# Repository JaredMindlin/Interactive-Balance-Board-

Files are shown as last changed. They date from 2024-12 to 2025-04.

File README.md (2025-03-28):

**Montessori Interactive Balance Board App**
This project is part of the Montessori Interactive Balance Board System, which aims to provide an engaging, technology-enhanced educational tool for children. The app serves as the primary interface for interacting with the system, enabling game selection, system control, and real-time status updates of connected devices.

**Features: ✅ Completed Features**<br /><br />

**System Control Dashboard:**
* Toggle system ON/OFF and manage connections to devices (ESP32 boards).
* Display the count of connected devices in real-time.
* Monitor and control the system's LED status.

**Game Modes:**<br />
Pathway Game: Guide the user from a starting point (green node) to a destination (red node) via blue LED pathways (placeholder created).<br />
Up Next Game: Sequentially guide the user through a series of dynamically changing nodes (placeholder created).<br />

**Database Integration:**
Real-time updates of system and game states using MongoDB.<br />
Persistent storage for:<br />
* System status (ON/OFF).
* Connected devices count.
* LED state.
* Selected game mode.

**Frontend-Backend Communication:**
* API integration between the React frontend and the Node.js/Express backend.
* Live updates to the backend state via Axios.

**ESP32 Hardware Perception and Output**
* Connected NeoPixel Strip and HC-SR01 ultrasonic distance sensors to the WSP32 Firebeetle using SPI and Arduino Libraries. The LED Strip reflects the distance detected by each distance sensor. 

**Wi-Fi/Bluetooth Integration: 🚧 In Progress**
* Communication between the app and the ESP32 server for real-time hardware interaction.
* Enable hardware-triggered events and feedback.

**Game Interactions:**
* Fully interactive gameplay tied to hardware input/output (e.g., LED activation and sensor feedback).
* Dependency on ESP32 connections and hardware setup.

**Installation and Setup:**

**Prerequisites**
* Node.js and npm/yarn installed on your system.
* MongoDB Atlas account or a locally hosted MongoDB instance.
* ESP32 with Arduino IDE configured for Wi-Fi/Bluetooth communication.

**Steps**
Clone the repository:
* git clone https://github.com/JaredMindlin/Interactive-Balance-Board-.git
* cd Interactive-Balance-Board

Install dependencies for both frontend and backend:
* cd montessori-app/frontend
* npm install
* cd ../backend
* npm install

Start the MongoDB database connection and backend server:
* cd ../backend
* node server.js

Start the frontend development server:
* cd ../frontend
* npm start

Access the app at http://localhost:3000 locally or http://'your.network.ip':3000.

**Usage**
* Navigate to the System Control page to manage the system's state and connected devices.
* Select a game mode from the Game Modes page. Changes will reflect in the database.
* Monitor real-time system updates and continue further Wi-Fi/Bluetooth integration.

**Future Goals**
* Finalize hardware communication for seamless interaction between the app and the ESP32 server.
* Enhance gameplay by incorporating live feedback from sensors and LEDs.
* Improve UI/UX based on user testing and feedback.

**All Known Bugs**
* Apart from placeholders for 'In Progress' work, inexpected behavior currently only lies in communicating with the ESP32 Server Board to actually track the real-time user data.<br />
* We have attempted to integrate the app to have access to HTTP requests made by the board to update the backend database and trigger the board to dequeue and sleep its process, however this feature has been moved under 'In Progress' by the team.
* When connected to battery, the LED strip randomly lights blue and purple when a close distance is detected. (More lights turn on) Likely due to a lack of power to the LED strip.

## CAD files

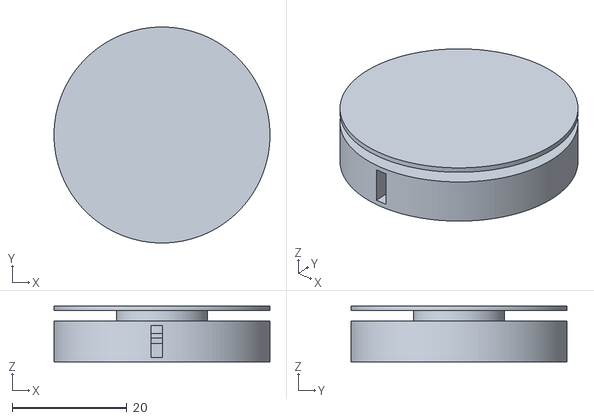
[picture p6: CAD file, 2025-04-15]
Models and Schematics/Velostat Sensor Case/Sensor Case Assembly.stl
37.6 x 37.6 x 9.71

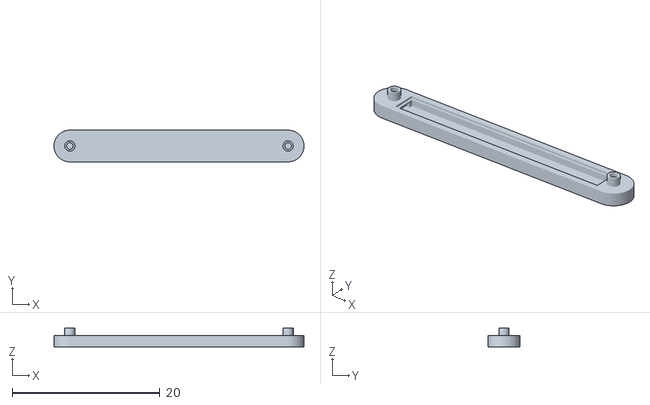
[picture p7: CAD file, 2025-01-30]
Models and Schematics/Montessori Board Model 0.1/Part Studio 1 - Part 1.stl
33.8 x 4.30 x 2.52

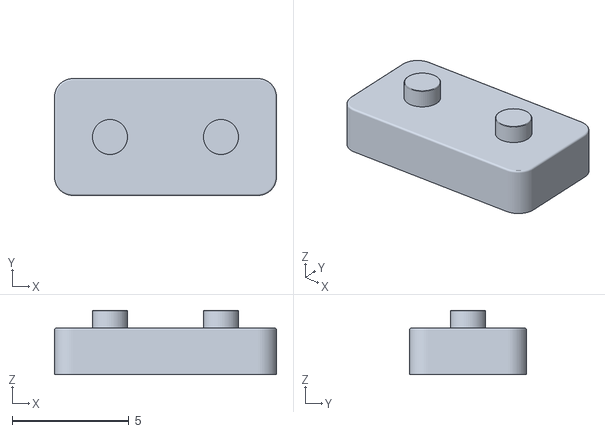
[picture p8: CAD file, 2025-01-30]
Models and Schematics/Montessori Board Model 0.2/Part Studio 1 - Base.stl
9.50 x 5.00 x 2.75

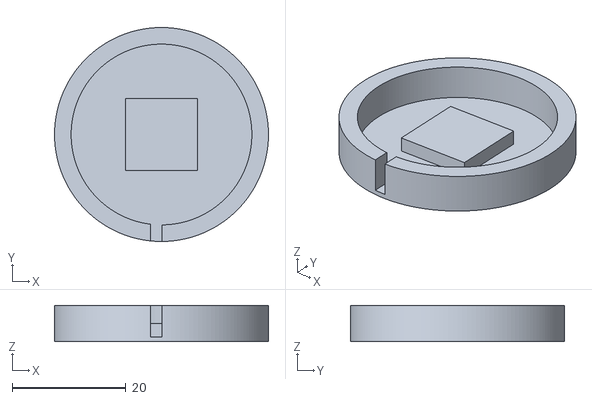
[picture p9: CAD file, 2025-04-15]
Models and Schematics/Velostat Sensor Case/Board - Sensor Base.stl
37.6 x 37.6 x 6.35

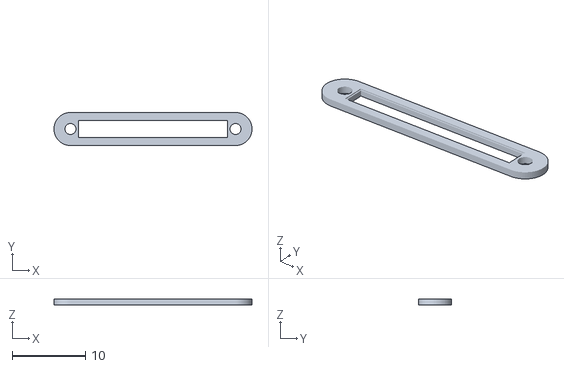
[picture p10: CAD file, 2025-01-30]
Models and Schematics/Montessori Board Model 0.2/Part Studio 1 - Top.stl
27.0 x 4.50 x 0.75

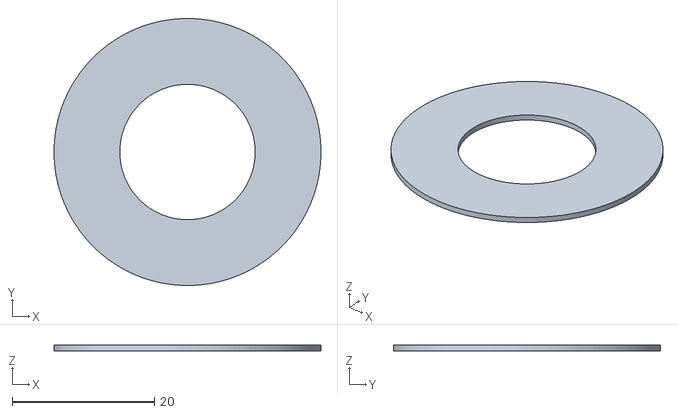
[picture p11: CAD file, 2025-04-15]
Models and Schematics/Velostat Sensor Case/Board - Sensor Lid.stl
37.6 x 37.6 x 0.794

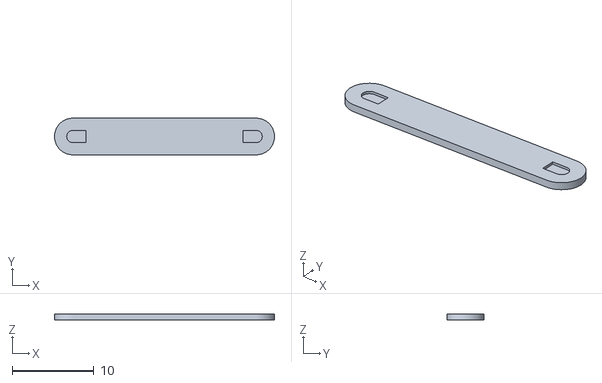
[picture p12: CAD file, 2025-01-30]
Models and Schematics/Montessori Board Model 0.2/Part Studio 1 - Bottom.stl
27.0 x 4.50 x 0.75

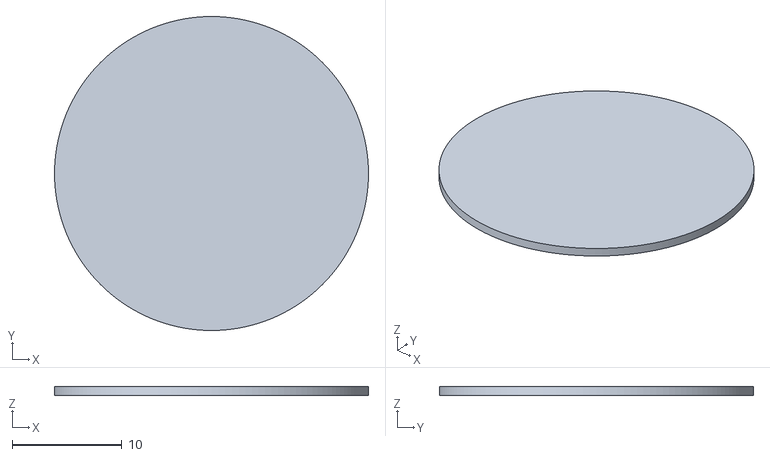
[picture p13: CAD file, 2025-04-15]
Models and Schematics/Velostat Sensor Case/Board - Velostat Top Pad.stl
28.6 x 28.6 x 0.794

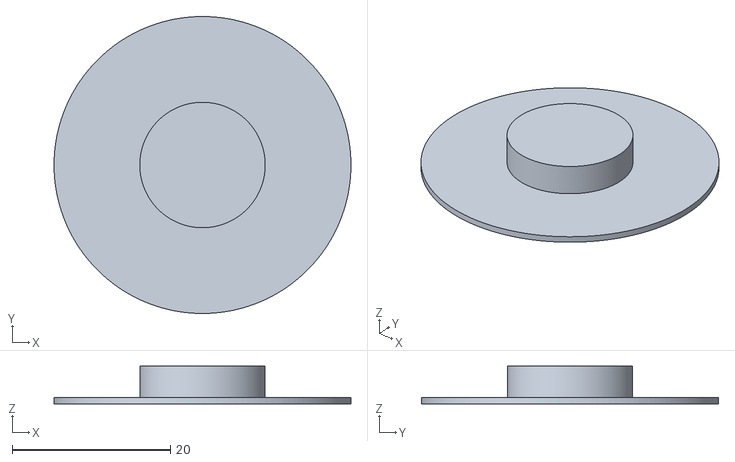
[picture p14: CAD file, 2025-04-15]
Models and Schematics/Velostat Sensor Case/Board - Sensor Top Pad.stl
37.6 x 37.6 x 4.76

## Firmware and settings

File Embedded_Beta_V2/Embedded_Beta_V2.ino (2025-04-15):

// Wifi Library/Header File
#include <WiFi.h>
// Http communication Library/Header File
#include <HTTPClient.h>
// JSON for Arduino Library/Header File
#include <ArduinoJson.h>
// Arduino LED Strip Library/Header File
#include <Adafruit_NeoPixel.h>
// Wifi Library Mananger for SSID and password security
#include <WiFiManager.h>
// String is Numeric Checker
#include <ctype.h>

#define PIN_NEO_PIXEL 2  // The ESP32 pin GPIO2 connected to NeoPixel
#define NUM_PIXELS 30     // The number of LEDs (pixels) on NeoPixel LED strip

// Node.JS Backend Server Routes
#define SERVER_URL "http://172.20.10.6:5000/update-device-count"

String ipAddress;
String GameAddress = ":5000/game-mode";
String BrightnessAddress = ":5000/brightness";
String FetchBoardIDAddress = ":5000/api/board/register-board";
String FetchBoardZeroDataAddress = ":5000/api/board/board-valid-data-zero";
String FetchBoardZeroEndAddress = ":5000/api/board/board-end-data-zero";
String FetchBoardOneDataAddress = ":5000/api/board/board-valid-data-one";
String FetchBoardOneEndAddress = ":5000/api/board/board-end-data-one";
String FetchBoardTwoDataAddress = ":5000/api/board/board-valid-data-two";
String FetchBoardTwoEndAddress = ":5000/api/board/board-end-data-two";


int pressurePin = A0;
Adafruit_NeoPixel NeoPixel(NUM_PIXELS, PIN_NEO_PIXEL, NEO_GRB + NEO_KHZ800);
int boardBrightness = 255;

// Define States for the State Machine for the boards
enum BoardStates {ON, CONNECTED, PATHWAY, UPNEXT};
BoardStates currentState = ON;

// Default Board ID before being assigned a real ID
int boardID = -1;

// Default GameMode (used for switching)
int lastGameMode = -1;
// Default Brightness
int currentBrightness = 255;
// Brightness Changes
int convBrightness = 100;
// Game Speed
int gameSpeed = 5000;

// Game Variables
bool isBoardValid = false;
bool isBoardEndPoint = false;

// Game Functions
void resetBoards() {
  currentState = CONNECTED;
  isBoardValid = false;
  isBoardEndPoint = false;
}

void youLose() {
  setLEDs(255, 0, 0); // Red
  delay(5000);
  resetBoards();
}

void youWin() {
  setLEDs(0, 255, 0); // Green
  delay(5000);
  resetBoards();
}

// Define Helper Functions
void updateRoutes() {
  GameAddress = "http://" + ipAddress + GameAddress;
  BrightnessAddress = "http://" + ipAddress + BrightnessAddress;
  FetchBoardIDAddress = "http://" + ipAddress + FetchBoardIDAddress;
  FetchBoardZeroDataAddress = "http://" + ipAddress + FetchBoardZeroDataAddress;
  FetchBoardZeroEndAddress = "http://" + ipAddress + FetchBoardZeroEndAddress;
  FetchBoardOneDataAddress = "http://" + ipAddress + FetchBoardOneDataAddress;
  FetchBoardOneEndAddress = "http://" + ipAddress + FetchBoardOneEndAddress;
  FetchBoardTwoDataAddress = "http://" + ipAddress + FetchBoardTwoDataAddress;
  FetchBoardTwoEndAddress = "http://" + ipAddress + FetchBoardTwoEndAddress;
  // Serial.println("Game Address: " + GameAddress);
  // Serial.println("Brightness Address: " + BrightnessAddress);
  // Serial.println("Fetch Board ID Address: " + FetchBoardIDAddress);
  // Serial.println("Fetch Board 0 Data Address: " + FetchBoardZeroDataAddress);
  // Serial.println("Fetch Board 0 End Address: " + FetchBoardZeroEndAddress);
  // Serial.println("Fetch Board 1 Data Address: " + FetchBoardOneDataAddress);
  // Serial.println("Fetch Board 1 End Address: " + FetchBoardOneEndAddress);
  // Serial.println("Fetch Board 2 Data Address: " + FetchBoardTwoDataAddress);
  // Serial.println("Fetch Board 2 End Address: " + FetchBoardTwoEndAddress);
}

void setLEDs(uint8_t r, uint8_t g, uint8_t b) {
  for (int pixel = 0; pixel < NUM_PIXELS; pixel++) {
      NeoPixel.setPixelColor(pixel, NeoPixel.Color(r, g, b));
  }
}

// Function that converts user input (1-100) into the range of (1-255)
void adjustBrightness(int &currBrightness, int nodePacket) {
  float conversion = (nodePacket / 100.0) * 255;
  currBrightness = (int)conversion;
  // Brightness is first applied
  NeoPixel.setBrightness(currBrightness);
}

void PathWayGameMode() {
  int sensorValue = analogRead(pressurePin);
  Serial.println(sensorValue);
  if (isBoardValid) {
    if (sensorValue > 300) {
      if (isBoardEndPoint) {
        youWin();
      }
      else {
        setLEDs(128, 0, 128); // Purple 
      }
    }
    else {
      setLEDs(0, 0, 255); // Blue
    }
  }
  else {
    if (sensorValue > 300) {
      youLose();
    }
  }
  delay(1000);
}

void UpNextGameMode() {
  int sensorValue = analogRead(pressurePin);
  Serial.println(sensorValue);
  if (isBoardEndPoint && sensorValue > 300) {
    youWin();
  }
  else {
    if (sensorValue > 300) {
      setLEDs(64, 224, 208); // Turqoise
    }
    else {
      setLEDs(255, 140, 0); // Dark Orange
    }
  }
  delay(1000);
}

// HTTP Post Function
void sendDataToServer() {
  if (WiFi.status() == WL_CONNECTED) {
    Serial.println("WiFi Connected, attempting HTTP POST...");

    HTTPClient http;
    http.begin(SERVER_URL);  // Ensure this URL is correct
    http.addHeader("Content-Type", "application/json");

    String jsonPayload = "{\"device\": \"ESP32\"}";
    Serial.print("Sending data: ");
    Serial.println(jsonPayload);

    int httpResponseCode = http.POST(jsonPayload);

    Serial.print("HTTP Response code: ");
    // If -1, request failed
    Serial.println(httpResponseCode);  
    http.end();
  }
  else {
    Serial.println("WiFi Disconnected, unable to send data.");
  }
}

// HTTP Post Function
void sendBoardStatusToServer(String boardID, bool isOccupied) {
  if (WiFi.status() == WL_CONNECTED) {
    HTTPClient http;
    http.begin(SERVER_URL);
    http.addHeader("Content-Type", "application/json");

    String jsonPayload = "{\"boardID\": \"" + boardID + "\", \"isOccupied\": " + (isOccupied ? "true" : "false") + "}";
    Serial.print("Sending data: ");
    Serial.println(jsonPayload);

    int httpResponseCode = http.POST(jsonPayload);
    Serial.print("HTTP Response code: ");
    // If -1, request failed
    Serial.println(httpResponseCode);  
    if (httpResponseCode == 200) {
      // We'll see where this goes
    }
    http.end();
  }
}

// HTTP Request for checking brightness
void fetchBrightness() {
  if (WiFi.status() == WL_CONNECTED) {
      HTTPClient http;
      http.begin(BrightnessAddress);
      
      int httpResponseCode = http.GET();  // Send GET request

      if (httpResponseCode > 0) {
          String response = http.getString();
          Serial.println("Brightness Response: " + response);
          String delimiter1 = ":";
          String delimiter2 = "}";
          int pos1 = response.indexOf(delimiter1);
          int pos2 = response.indexOf(delimiter2, pos1 + 1); // Start searching after the first delimiter
          String substring = response.substring(pos1 + 1, pos2);
          int brightness = substring.toInt();
          if (brightness >= 1 && brightness <= 100 && brightness != convBrightness) {
            adjustBrightness(currentBrightness, brightness);
            convBrightness = brightness;
            Serial.printf("New Brightness: %d\n", brightness);
          }
      }
      else {
        Serial.println("HTTP Request for brightness failed");
      }    
      http.end();
  } 
  else {
    Serial.println("WiFi Disconnected - Brightness");
  }
}

// HTTP request for game mode
void fetchGameMode() {
    if (WiFi.status() == WL_CONNECTED) {
      HTTPClient http;
      http.begin(GameAddress);
      int httpResponseCode = http.GET();  // Send GET request
      int tempGameMode = lastGameMode; // Variable to prevent constant gamemode reassignment
      if (httpResponseCode > 0) {
        String response = http.getString();
        if (response.equals("{\"gameModeSelected\":\"Pathway\"}")) {
          lastGameMode = 1;
        }
        else if (response.equals("{\"gameModeSelected\":\"UpNext\"}")) {
          lastGameMode = 2;
        }
        else {
          lastGameMode = 0;
        }
        if (tempGameMode != lastGameMode) {
          switch (lastGameMode) {
          case 0:
            currentState = CONNECTED;
            break;
          case 1:
          // GET PULL BOARD DATA
            fetchBoardData();
            currentState = PATHWAY;
            break;
          case 2:
            // GET PULL BOARD DATA
            fetchBoardData();
            currentState = UPNEXT;
            break;
          default:
            currentState = CONNECTED;
            break;
          }
        }
      }
      else {
        Serial.println("HTTP Request failed");
      }
      http.end();
  } 
  else {
    Serial.println("WiFi Disconnected - Gamemode");
  }
}

// HTTP Request for assigning boardID
void fetchBoardID() {
  if (WiFi.status() == WL_CONNECTED) {
      HTTPClient http;
      http.begin(FetchBoardIDAddress);
      
      int httpResponseCode = http.GET();  // Send GET request
      if (httpResponseCode > 0) {
        String response = http.getString();
        Serial.println("ID Response: " + response);
        char capture = response.substring(response.length() - 2, response.length() - 1).charAt(0);
        if (isdigit(capture)) {
          int tempID = capture - '0';
          Serial.printf("Captured Number: %d\n", tempID);
          if (boardID == -1) {
            boardID = tempID;
          }
        }
      }
      else {
        Serial.println("HTTP Request for boardID failed");
      }
      http.end();
  } 
  else {
    Serial.println("WiFi Disconnected - BoardID");
  }
}

// HTTP Request for retreiving the vector of valid boards
void fetchBoardData() {
  if (WiFi.status() == WL_CONNECTED) {
    String delimiter1 = ":";
    String delimiter2 = "}";
    int pos1;
    int pos2;
    String substring;
    HTTPClient http;
    if (boardID == 0) {
      http.begin(FetchBoardZeroDataAddress);
    }
    else if (boardID == 1) {
      http.begin(FetchBoardOneDataAddress);
    }
    else if (boardID == 2) {
      http.begin(FetchBoardTwoDataAddress);
    }
    int httpResponseCode = http.GET();  // Send GET request
    if (httpResponseCode > 0) {
      String response = http.getString();
      pos1 = response.indexOf(delimiter1);
      pos2 = response.indexOf(delimiter2, pos1 + 1);
      substring = response.substring(pos1 + 1, pos2);
      isBoardValid = substring.toInt();
      Serial.printf("Valid Data: %d\n", isBoardValid);
    }
    else {
      Serial.println("HTTP Request for Valid Boards failed");
    }

    http.end();

    if (boardID == 0) {
      http.begin(FetchBoardZeroEndAddress);
    }
    else if (boardID == 1) {
      http.begin(FetchBoardOneEndAddress);
    }
    else if (boardID == 2) {
      http.begin(FetchBoardTwoEndAddress);
    }
    httpResponseCode = http.GET();  // Send GET request
    if (httpResponseCode > 0) {
      String response = http.getString();
      pos1 = response.indexOf(delimiter1);
      pos2 = response.indexOf(delimiter2, pos1 + 1);
      substring = response.substring(pos1 + 1, pos2);
      isBoardEndPoint = substring.toInt();
      Serial.printf("End Data: %d\n", isBoardEndPoint);
    }
    else {
      Serial.println("HTTP Request for End Boards failed");
    }
    http.end();
  } 
  else {
    Serial.println("WiFi Disconnected - End Boards");
  }
}

void setup() {
  // Baud rate
  Serial.begin(115200);
  // Pin set up
  pinMode(pressurePin, INPUT_PULLUP);
  setLEDs(0, 0, 0);
  NeoPixel.begin();
  // Initialize WiFi Manager
  WiFiManager wm;
  // Try to connect to last known connection
  if (!wm.autoConnect("User SSID", "User Password")) {
    Serial.print("failed to connect and hit timeout");
    ESP.restart();
    delay(1000);
  }
  // Wait on connection
  while (WiFi.status() != WL_CONNECTED) {
      delay(1000);
      Serial.print(".");
  }
  String iptemp = WiFi.localIP().toString();
  Serial.println("\nConnected to WiFi with Local IP: " + iptemp);
  iptemp[WiFi.localIP().toString().length() - 1] = '6';
  ipAddress = iptemp;
  Serial.println("\nRoute IP: " + ipAddress);
  updateRoutes();
  // Assign this board a unique ID
  fetchBoardID();
  // Update Device Count
  sendDataToServer();
  delay(2000);
}

void loop() {
  // Check for gamemode
  fetchGameMode();
  // Check for brightness
  fetchBrightness();
  // Perform Hardware functions
  switch (currentState) {
    case ON:
      Serial.print("Current State: ON\n");
      setLEDs(0, 0, 0);  // LED OFF
      break;
    case CONNECTED:
      Serial.print("Current State: CONNECTED\n");
      isBoardValid = false;
      isBoardEndPoint = false;
      setLEDs(255, 255, 255); // White LED
      break;
    case PATHWAY:
      Serial.print("Current State: PATHWAY\n");
      PathWayGameMode();
      break;
    case UPNEXT:
      Serial.print("Current State: UPNEXT\n");
      UpNextGameMode();
      break;
  }
  Serial.printf("BoardID: %d\n", boardID);
  Serial.printf("Valid Boolean: %d\n", isBoardValid);
  Serial.printf("End Boolean: %d\n", isBoardEndPoint);
  NeoPixel.show();
  Serial.printf("End of loop reached\n");
  delay(3000);
}

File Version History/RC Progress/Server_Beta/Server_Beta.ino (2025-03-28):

// BLE Server Library/Header Files
#include <BLEDevice.h>
#include <BLEUtils.h>
#include <BLEServer.h>
// Wifi Library/Header File
#include <WiFi.h>
// Http communication Library/Header File
#include <HTTPClient.h>
// JSON
#include <ArduinoJson.h>
// Unordered Map that stores the Connected Boards
#include <unordered_map>

// ID used to uniquely identify infomration
#define SERVICE_UUID "12345678-1234-5678-1234-56789abcdef0"
#define CHARACTERISTIC_UUID "87654321-4321-6789-4321-abcdef987654"
#define BRIGHTNESS_CHARACTERISTIC_UUID "abcdef12-3456-7890-abcd-ef1234567890"
#define BOARD_ID_CHARACTERISTIC_UUID "13579ace-2468-bdf0-1357-9ace2468bdf0"


#define SSID "Bruno iPhone"
#define PASSWORD "bruhbutton"
#define SERVER_URL "http://172.20.10.4:5000/update-device-count"

// Unordered Set that holds IDs of connected boards
std::unordered_map<int, bool> activeBoards;
// Unordered Map that holds connections to boards
std::unordered_map<int, BLERemoteCharacteristic*> boardCharacteristics;

// Default GameMode (used for switching)
int lastGameMode = -1;
// Default Brightness
int currentBrightness = 255;
// Next Available Ticket Counter
int nextTicket = 1;

BLECharacteristic *pCharacteristic;
BLECharacteristic *pBrightnessCharacteristic;
BLECharacteristic *pBoardIdCharacteristic;
BLEServer *pServer;
bool deviceConnected = false;

// Server object that the client boards will connunicate to
class ServerCallbacks : public BLEServerCallbacks {
  // Status for when the client board has connected
  void onConnect(BLEServer* pServer) override {
    Serial.println("Client Connected");
    deviceConnected = true;

    // Assign the board an ID
    int assignedID = -1;
    for (unsigned int i = 1; i < nextTicket; i++) {
      if (activeBoards.find(i) == activeBoards.end()) {
        assignedID = i;
        // Default construction
        activeBoards.emplace(i, false);
        break; 
      }
    }

    if (assignedID == -1) {
      assignedID = nextTicket;
      activeBoards.emplace(nextTicket, false);
      nextTicket++;
    }
    Serial.printf("Assigned Board ID: %d\n", assignedID);
    // Notify the client of its ID via existing characteristic
    String idMsg = "ID:" + String(assignedID);
    pCharacteristic->setValue(idMsg.c_str());  // Broadcast to all (client will filter)
    Serial.printf("Assigned Board ID: %d\n", assignedID);
  }
  // Status for when the client board has disconnected
  void onDisconnect(BLEServer* pServer) override {
    // Serial.println("Client Disconnected, restarting advertising...");
    deviceConnected = false;
    pServer->startAdvertising();
  }
};

// HTTP Post Function
void sendDataToServer() {
  if (WiFi.status() == WL_CONNECTED) {
    Serial.println("WiFi Connected, attempting HTTP POST...");

    HTTPClient http;
    http.begin(SERVER_URL);  // Ensure this URL is correct
    http.addHeader("Content-Type", "application/json");

    String jsonPayload = "{\"device\": \"ESP32\"}";
    Serial.print("Sending data: ");
    Serial.println(jsonPayload);

    int httpResponseCode = http.POST(jsonPayload);

    Serial.print("HTTP Response code: ");
    // If -1, request failed
    Serial.println(httpResponseCode);  

    http.end();
  }
  else {
    Serial.println("WiFi Disconnected, unable to send data.");
  }
}

// HTTP Post Function
void sendBoardStatusToServer(String boardID, bool isOccupied) {
  if (WiFi.status() == WL_CONNECTED) {
    HTTPClient http;
    http.begin(SERVER_URL);
    http.addHeader("Content-Type", "application/json");

    String jsonPayload = "{\"boardID\": \"" + boardID + "\", \"isOccupied\": " + (isOccupied ? "true" : "false") + "}";
    Serial.print("Sending data: ");
    Serial.println(jsonPayload);

    int httpResponseCode = http.POST(jsonPayload);
    Serial.print("HTTP Response code: ");
    // If -1, request failed
    Serial.println(httpResponseCode);  
    if (httpResponseCode == 200) {
      String bleMsg = "ID:" + boardID + ":Pathway";  // Or include brightness
      pCharacteristic->setValue(bleMsg.c_str());
      Serial.println("Broadcasted: " + bleMsg);
    }
    http.end();
  }
}

int fetchBrightness() {
  if (WiFi.status() == WL_CONNECTED) {
      HTTPClient http;
      http.begin("http://172.20.10.4:5000/brightness");
      
      int httpResponseCode = http.GET();  // Send GET request

      if (httpResponseCode > 0) {
          String response = http.getString();
          Serial.println("Brightness Response: " + response);
          String delimiter1 = ":";
          String delimiter2 = "}";
          int pos1 = response.indexOf(delimiter1);
          int pos2 = response.indexOf(delimiter2, pos1 + 1); // Start searching after the first delimiter
          String substring = response.substring(pos1 + 1, pos2);
          int brightness = substring.toInt();
          if (brightness >= 1 && brightness <= 100) {
            return brightness;
          }
      }
      else {
        Serial.println("HTTP Request for brightness failed");
      }    
      http.end();
  } 
  else {
    Serial.println("WiFi Disconnected");
  }
  return -1;
}

// HTTP Get Function
int fetchGameMode() {
    if (WiFi.status() == WL_CONNECTED) {
        HTTPClient http;
        http.begin("http://172.20.10.4:5000/game-mode");
        
        int httpResponseCode = http.GET();  // Send GET request

        if (httpResponseCode > 0) {
            String response = http.getString();
            Serial.println(response);
            int gameMode = 0;
            if (response.equals("{\"gameModeSelected\":\"Pathway\"}")) {
              gameMode = 1;
            }
            else if (response.equals("{\"gameModeSelected\":\"UpNext\"}")) {
              gameMode = 2;
            }
            http.end();
            return gameMode;
        }
        else {
          Serial.println("HTTP Request failed");
        }
        http.end();
    } 
    else {
      Serial.println("WiFi Disconnected");
    }
    return -1;  // Return -1 if request fails
}
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

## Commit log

2024-12-02 Distance Sensor and NeoPixel with SPI git rm --cached Interactive-Balance-Board-# On branch Jared_Hardware
2025-01-29 Added hardware schemati
    [Montessori_Schematic.kicad_sch]
2025-01-30 Velostat pressure sensor code
2025-01-30 Added Models and Schematics
    [Montessori_Schematic.kicad_sch, Part Studio 1 - Base.stl, Part Studio 1 - Bottom.stl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]
2025-01-31 Current BLE Integration with Server Board Underway
    Also updated previous attempt at connection with server board through WIFI
2025-03-05 Add files via upload
    Fixed memory leak in updateState()
    [Embedded_Beta.ino]
2025-03-26 Upload of current build just in case
2025-04-11 board data routes
2025-04-14 reset button v1
2025-04-14 Fixed Fetch not updating board data
    [Embedded_Beta_V2.ino]
2025-04-15 Updated Models and Schematics
    [Board - Sensor Base.stl, Board - Sensor Lid.stl, Board - Sensor Top Pad.stl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]
